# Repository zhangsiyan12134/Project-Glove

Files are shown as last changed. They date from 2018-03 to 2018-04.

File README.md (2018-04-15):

# Project-Glove<br />
This project is to create a hand glove that capture motions to control a computer or other
devices. It will increase capacity of control in VR and other computer systems. The range of
motion will change from pushing buttons and triggers to active movements of the hands.

This is a 2nd Year Engineeing Design II Group Project at Acadia University.<br />

**Group 12**<br />

Omar H. Khattab/ Project Manager<br />
Hannah MacCormnack/ Project Researcher<br />
Haolin Song/ Project Designer<br />
Siyan Zhang/ Project Technican<br />

**Current State**<br />
The basic function of mouse is working, but due to the limited performance and pooly optimized code, add any additional function will causes signifecant delay of the motion.

**Todo List**<br />
1. Simplify the code to make code more efficiency.
2. Waiting for **New** ATSAMD51 series with hardware DSP and Float Point support.

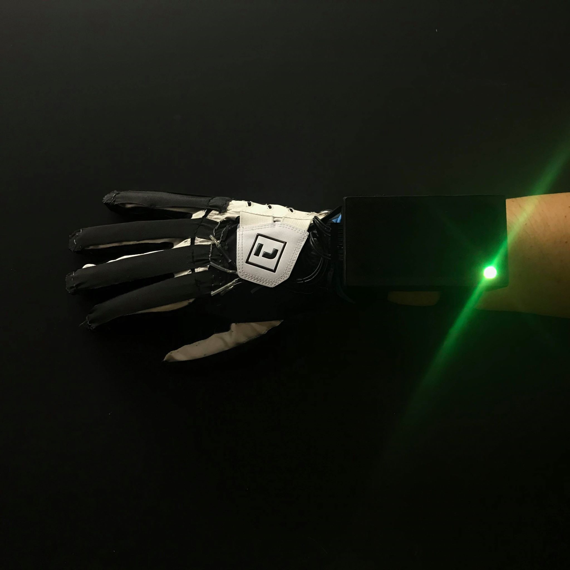
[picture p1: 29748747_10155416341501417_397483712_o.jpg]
Image of Glove


Demo Video：https://youtu.be/c8829fM5WGY

**Parts List**<br />

Part     Value          Device             Package         Library           Sheet<br />

MS1                     FEATHERM0BLE       FEATHER         adafruit          1<br />
U$1                     Adafruit BNO055    BNO055          Adafruit_BNO055   1<br />
MODESW                  OS102011MA1Q       OS102011MA1Q    adafruit          1<br />
PSW                     OS102011MA1Q       OS102011MA1Q    adafruit          1<br />
D1       CLEAR          LED-RGB-CACLEAR    LED-RGB-THRU    SparkFun-LED      1<br />
R1       200            R-US_0207/7        0207/7          resistor          1<br />
R2       200            R-US_0207/7        0207/7          resistor          1<br />
R3       200            R-US_0207/7        0207/7          resistor          1<br />
R4       10k            R-US_0207/7        0207/7          resistor          1<br />
R5       10k            R-US_0207/7        0207/7          resistor          1<br />
R6       10k            R-US_0207/7        0207/7          resistor          1<br />
R7       10k            R-US_0207/7        0207/7          resistor          1<br />
JP1                     PINHD-1X8          1X08            pinhead           1<br />

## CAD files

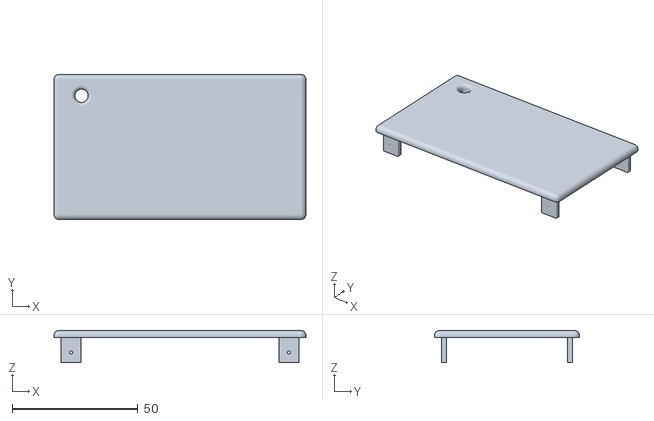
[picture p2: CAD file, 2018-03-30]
Case Design/Top Cover.stl
100.0 x 57.6 x 12.8

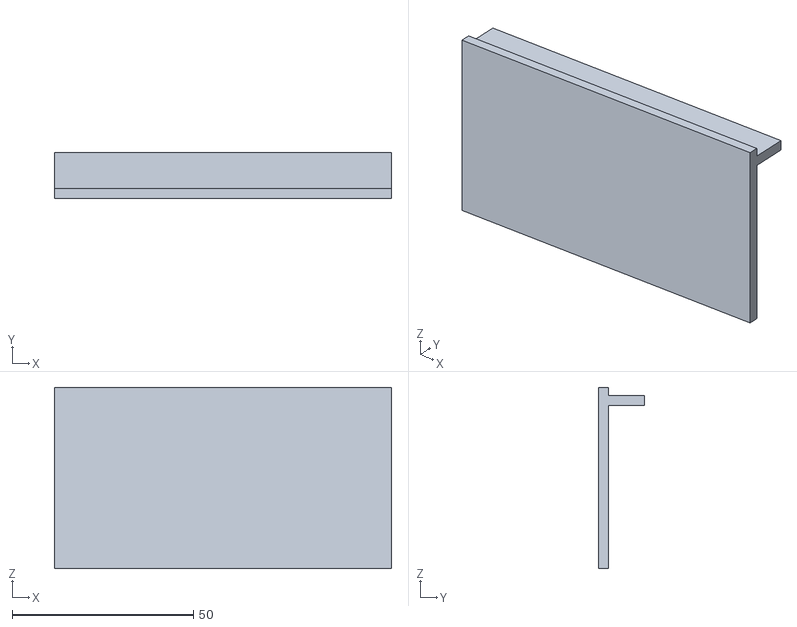
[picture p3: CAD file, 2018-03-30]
Case Design/Insert.stl
93.0 x 12.8 x 50.0

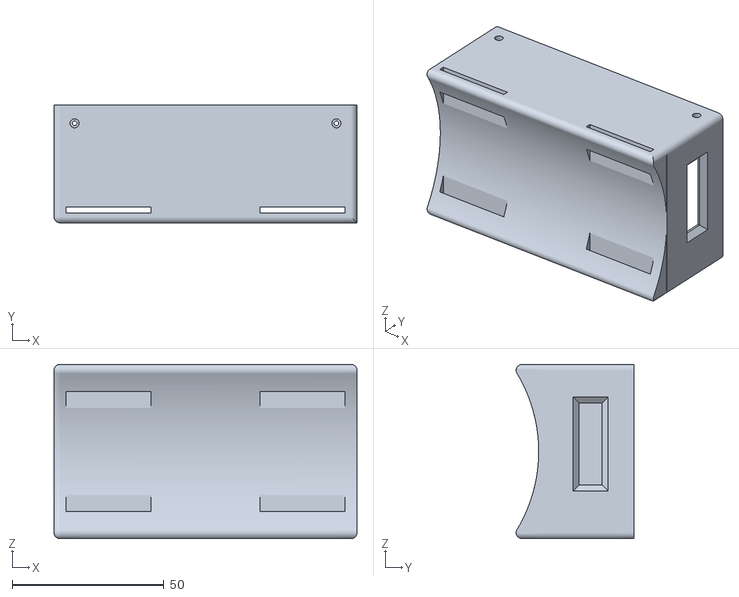
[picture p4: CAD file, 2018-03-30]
Case Design/Body.stl
100.0 x 38.8 x 57.6

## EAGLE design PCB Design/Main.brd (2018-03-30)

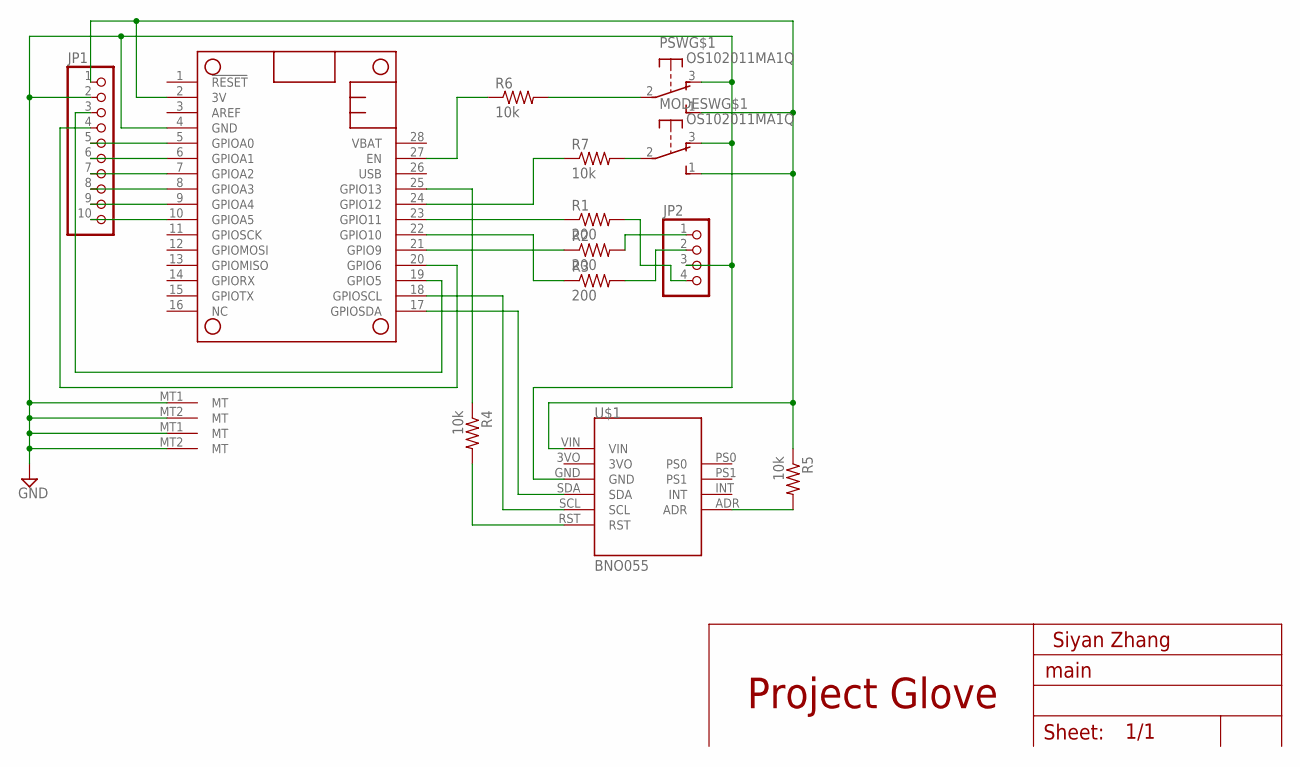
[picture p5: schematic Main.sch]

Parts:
JP1: PINHD-1X10; 1X10
JP2: PINHD-1X4; 1X04
MODESW: OS102011MA1Q
MS1: FEATHERWING
PSW: OS102011MA1Q
R1, R2, R3: 200; 0207/7
R4, R6, R7: 10k; 0207/7
R5: 10k; 0207/15
U$1: BNO055

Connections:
3V: JP1.1, MODESW.1 (S), MS1.2 (3V), PSW.1 (S), R5.1, U$1.VIN
GND: JP1.2, JP2.3, MODESW.3 (O), MODESW.MT1 (MT), MODESW.MT2 (MT), MS1.4 (GND), PSW.3 (O), PSW.MT1 (MT), PSW.MT2 (MT), U$1.GND
unnamed: MODESW.2, R7.2
unnamed: MS1.24 (GPIO12), R7.1
unnamed: MS1.22 (GPIO10), R3.1
unnamed: MS1.21 (GPIO9), R2.1
unnamed: MS1.23 (GPIO11), R1.1
unnamed: JP2.4, R1.2
unnamed: JP2.1, R2.2
unnamed: JP2.2, R3.2
unnamed: JP1.10, MS1.10 (GPIOA5)
unnamed: JP1.9, MS1.9 (GPIOA4)
unnamed: JP1.8, MS1.8 (GPIOA3)
unnamed: JP1.7, MS1.7 (GPIOA2)
unnamed: JP1.6, MS1.6 (GPIOA1)
unnamed: MS1.17 (GPIOSDA), U$1.SDA
unnamed: MS1.18 (GPIOSCL), U$1.SCL
unnamed: R4.2, U$1.RST
unnamed: R5.2, U$1.ADR
unnamed: MS1.25 (GPIO13), R4.1
unnamed: JP1.5, MS1.5 (GPIOA0)
unnamed: PSW.2, R6.2
unnamed: MS1.27 (EN), R6.1
unnamed: JP1.3, MS1.19 (GPIO5)
unnamed: JP1.4, MS1.20 (GPIO6)

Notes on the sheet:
Sheet:
Project Glove
Siyan Zhang

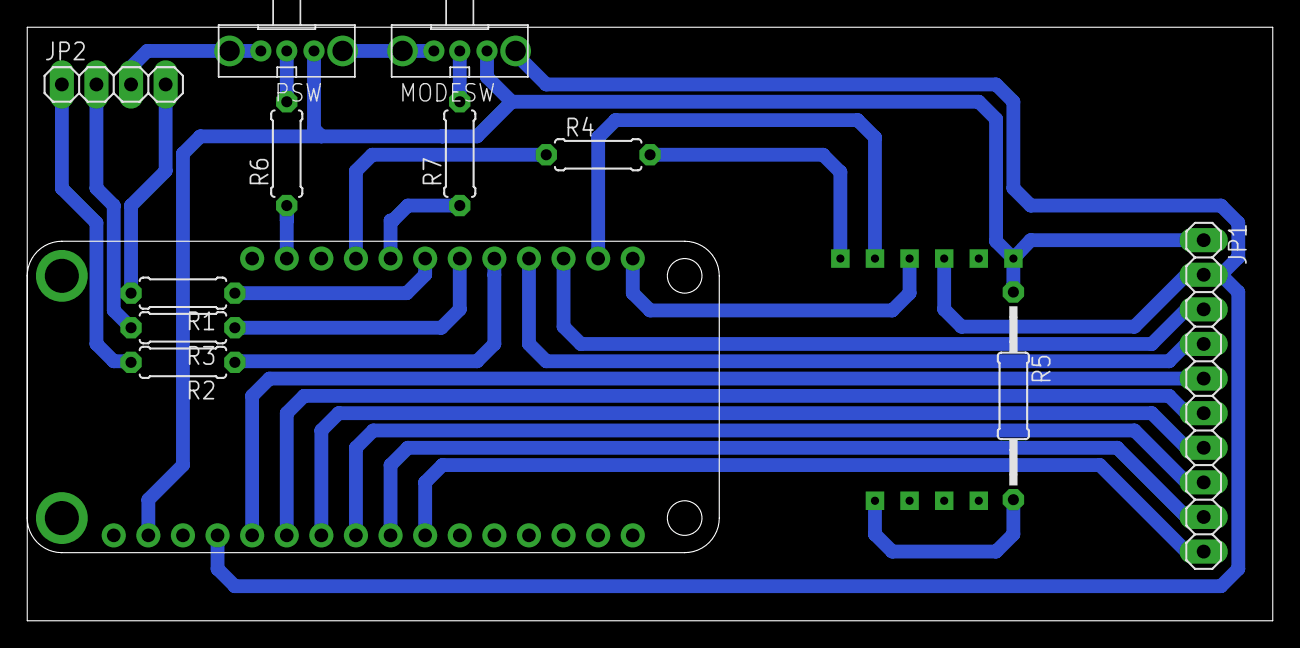
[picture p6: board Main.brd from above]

Board: 2 copper layers, 91.4 x 43.6 mm, 14 parts (0 on the bottom side), 25 nets.

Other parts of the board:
U$2: A4L-LOC

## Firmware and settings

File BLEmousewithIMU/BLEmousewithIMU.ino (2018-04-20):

/*
This is the program for Adafruit Feather M0 Bluefruit LE with Adafruit BNO055 IMU Module.
In theory, it can be directly uses on Arduino M0 with Adafruit Bluefruit LE SPI Friend and Adafruit BNO055 IMU Module.
*/

//include libraries for microcontroller and BLE module
#include "BluefruitConfig.h"
#include <Arduino.h>
#include <SPI.h>
#include "Adafruit_BLE.h"
#include "Adafruit_BluefruitLE_SPI.h"
#include "Adafruit_BluefruitLE_UART.h"

//include libraries for IMU
#include <Wire.h>
#include <Adafruit_Sensor.h>
#include <Adafruit_BNO055.h>
#include <utility/imumaths.h>

//Set IMU sample rate and rename the sensor in bno
#define BNO055_SAMPLERATE_DELAY_MS (10)
Adafruit_BNO055 bno = Adafruit_BNO055();

//define all the pin numbers

#define thumb A1
#define index A2
#define middle A3
#define ring A4
#define pinky A5

#define ModeSW 12

#define rgbRed 11
#define rgbGreen 10
#define rgbBlue 9

//settings for the project
const int sensitivity = 22; //sensitivity of the movement
const int debug = 1; //Debug flag

//initialize all global variables 
int xMove, yMove, drift, b;
float _x0, _y0;
float _x1, _y1, _z1, _x2, _y2;

/*=========================================================================
    APPLICATION SETTINGS

    FACTORYRESET_ENABLE       Perform a factory reset when running this sketch
   
                              Enabling this will put your Bluefruit LE module
                              in a 'known good' state and clear any config
                              data set in previous sketches or projects, so
                              running this at least once is a good idea.
   
                              When deploying your project, however, you will
                              want to disable factory reset by setting this
                              value to 0.  If you are making changes to your
                              Bluefruit LE device via AT commands, and those
                              changes aren't persisting across resets, this
                              is the reason why.  Factory reset will erase
                              the non-volatile memory where config data is
                              stored, setting it back to factory default
                              values.
       
                              Some sketches that require you to bond to a
                              central device (HID mouse, keyboard, etc.)
                              won't work at all with this feature enabled
                              since the factory reset will clear all of the
                              bonding data stored on the chip, meaning the
                              central device won't be able to reconnect.
    MINIMUM_FIRMWARE_VERSION  Minimum firmware version to have some new features
    -----------------------------------------------------------------------*/
    #define FACTORYRESET_ENABLE         0
    #define MINIMUM_FIRMWARE_VERSION    "0.6.6"
/*=========================================================================*/


// Create the bluefruit object, either software serial...uncomment these lines

/* ...hardware SPI, using SCK/MOSI/MISO hardware SPI pins and then user selected CS/IRQ/RST */
Adafruit_BluefruitLE_SPI ble(BLUEFRUIT_SPI_CS, BLUEFRUIT_SPI_IRQ, BLUEFRUIT_SPI_RST);

// A small helper
void error(const __FlashStringHelper*err) {
  Serial.println(err);
  while (1);
}

/**************************************************************************/
/*!
    @brief  Sets up the HW an the BLE module (this function is called
            automatically on startup)
*/
/**************************************************************************/

int getBattery(void){
//Convert battery voltage into 0~255 reading	
	int value;
	value = (analogRead(A7)*6.6/4096);
	return map(value, 3.2, 4.2, 0, 255);
}

int LEDWrite(int R, int G){
//lit RGB LED with Green and Red.	
	analogWrite(rgbRed, R);
	analogWrite(rgbGreen, G);
}

int FadeIn(int Pin){
  //Lit cycle for RGB LED throught mixture of red, green and blue
  for (int fadeValue = 0 ; fadeValue <= 255; fadeValue += 5) {
    // sets the value (range from 0 to 255):
    analogWrite(Pin, fadeValue);
    // wait for 30 milliseconds to see the dimming effect
    delay(30);
  }
  return 0;
}

int FadeOut(int Pin){
//Off cycle for RGB LED throught mixture of red, green and blue
  for (int fadeValue = 255 ; fadeValue >= 0; fadeValue -= 5) {
    // sets the value (range from 0 to 255):
    analogWrite(Pin, fadeValue);
    // wait for 30 milliseconds to see the dimming effect
    delay(30);
  }
  return 0;    
}

int cmove(int x, int y){
//send move data of mouse curser to bluetooth module according to the given x,y value.
     ble.print(F("AT+BleHidMouseMove="));
     ble.print(x);
     ble.print(",");
     ble.println(y);
     return 0;
}

int fingerRead(int finger, int offset){
//read one finger and give back a reading inbetween 0~4095
  int reading;
  reading = analogRead(finger)-offset;

  return reading; //map(reading,0,4095,0,512);
}

int LeftClick(void){
/*
Read fingers and compare to the thresholds, adjust thresholds and fingers with debug flag enabled.
Reading from finger is in between 0 to 4095.
All five fingers are avaliable as input(thumb, index, middle, ring and pinky).
*/
  int data = 0;
  for( int i=0; i <= 10; i++){
    if(fingerRead(middle, 0)> 2000 && fingerRead(ring, 0)> 2300){
	data += 1;
     } else {
	data += 0;
     }
  }
  /*
  to filter the noise, the following lines are averaging how many reading is higher
  than the thresholds in given numbers of continuous samples to be considered as a valid 
  click. (in this case 85% reading has to be higher than thresholds in 10 continuous 
  samples)  
  */
  if(data/10 >= 0.85){
	return 1;
  } else {
	return 0;
  }
}

void setup(void){

  while (!Serial and debug);  // required for Flora & Micro
  delay(500);

  Serial.begin(115200);

  pinMode(ModeSW,INPUT);
  
  ADC->INPUTCTRL.bit.GAIN = ADC_INPUTCTRL_GAIN_2X_Val; //Set internal gain
  ADC->REFCTRL.bit.REFSEL = ADC_REFCTRL_REFSEL_INTVCC0_Val;
  //ADC->AVGCTRL.bit.SAMPLENUM = ADC_AVGCTRL_SAMPLENUM_8_Val; // average from 4 samples
  analogReadResolution(12); //Change the ADC resolution to 12 bits 

  //initialize IMU module
  if(!bno.begin())
  {
    /* There was a problem detecting the BNO055 ... check your connections */
    Serial.print("Ooops, no BNO055 detected ... Check your wiring or I2C ADDR!");
    while(1);
  }
  bno.setExtCrystalUse(true); //set IMU module to use external crystal 

  //Initialise the BLU module
  Serial.print(F("Initialising the Bluefruit LE module: "));

  if ( !ble.begin(VERBOSE_MODE) ) //
  {
    error(F("Couldn't find Bluefruit, make sure it's in CoMmanD mode & check wiring?"));
  }
  Serial.println( F("OK!") );

  if ( FACTORYRESET_ENABLE )
  {
    /* Perform a factory reset to make sure everything is in a known state */
    Serial.println(F("Performing a factory reset: "));
    if ( ! ble.factoryReset() ){
      error(F("Couldn't factory reset"));
    }
  }

  /* Disable command echo from Bluefruit */
  ble.echo(false);

  Serial.println("Requesting Bluefruit info:");
  /* Print Bluefruit information */
  ble.info();

  // This demo only available for firmware from 0.6.6
  if ( !ble.isVersionAtLeast(MINIMUM_FIRMWARE_VERSION) )
  {
    error(F("This sketch requires firmware version " MINIMUM_FIRMWARE_VERSION " or higher!"));
  }

  /* Enable HID Service (including Mouse) */
  Serial.println(F("Enable HID Service (including Mouse): "));
  if (! ble.sendCommandCheckOK(F( "AT+BleHIDEn=On"  ))) {
    error(F("Failed to enable HID (firmware >=0.6.6?)"));
  }

  /* Add or remove service requires a reset */
  Serial.println(F("Performing a SW reset (service changes require a reset): "));
  if (! ble.reset() ) {
    error(F("Could not reset??"));
  }
  Serial.println();
    
}

/**************************************************************************/
/*!
    @brief  Constantly poll for new command or response data
*/
/**************************************************************************/
void loop(void){
//Two main loops for enable and disable function	
  while(digitalRead(ModeSW) == 1){

    imu::Vector<3> euler = bno.getVector(Adafruit_BNO055::VECTOR_EULER); //get euler angle from IMU

    _x1 = (euler.x());
    _y1 = (euler.y());
    _z1 = (euler.z());

    _y2 = _y1- _y0;  //compare the current reading to previous reading to see how far hand was moved
    _x2 = _x1- _x0;
    _y0 = _y1;  //Store current readings for next cycle
    _x0 = _x1; 
	
    if (_y2 != 0 or _x2 != 0){
	xMove = _x2 * sensitivity * 1.5;  //screen has greater length than width, times 1.5
        yMove = -(_y2) * sensitivity * 1;
	//remove slight drifting when hand is not moving.    
	if(yMove > 0){
		drift = 1;
	} else if(yMove < 0){
		drift = -1;
	} else {drift = 0;}
		
	if(xMove > 0){
		drift = 1;
	} else if(xMove < 0){
		drift = -1;
	} else {drift = 0;}
		
        cmove(xMove-drift, yMove-drift); // send data and move mouse
	}
	
    /******************************************************/
    /*if (_y2 != 0){
        yMove = -(_y2) * sensitivity * 1.8;
		if(yMove > 0){
			drift = 1;
		} else if(yMove < 0){
			drift = -1;
		} else {drift = 0;}
		
        cmove(0, yMove-drift); // move mouse on y axis
	}
	  
    if (_x2 != 0){
        xMove = _x2 * sensitivity;
		if(xMove > 0){
			drift = 1;
		} else if(xMove < 0){
			drift = -1;
		} else {drift = 0;}
		cmove(xMove-drift, 0); // move mouse on x axis
	}*/
	/******************************************************/
    
    if(LeftClick() == 1){
      ble.sendCommandCheckOK(F("AT+BleHidMouseButton=L,press"));
    }
    if(LeftClick() == 0){
      ble.sendCommandCheckOK(F("AT+BleHidMouseButton=0"));
    }
	
    if(debug){
    //print real time reading to serial port(may lagging the movement)
	Serial.print(xMove-drift);
	Serial.print(",");
	Serial.print(yMove-drift);
	Serial.print(",");
	Serial.print(fingerRead(index, 0));
	Serial.print(",");
	Serial.print(fingerRead(middle, 0));
	Serial.print(",");
	Serial.print(fingerRead(ring, 0));
	Serial.print(",");
	Serial.println(LeftClick());
    }
  }  
  //second main loop
  while(digitalRead(ModeSW) == 0){
	FadeIn(rgbRed);
	delay(1000);
	FadeIn(rgbGreen);
	delay(1000);
	FadeIn(rgbBlue);
	delay(1000);

	FadeOut(rgbRed);
	delay(1000);
	FadeOut(rgbGreen);
	delay(1000);
	FadeOut(rgbBlue);
	delay(1000);
  }
}

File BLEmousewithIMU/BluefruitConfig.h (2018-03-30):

// COMMON SETTINGS
// ----------------------------------------------------------------------------------------------
// These settings are used in both SW UART, HW UART and SPI mode
// ----------------------------------------------------------------------------------------------
#define BUFSIZE                        128   // Size of the read buffer for incoming data
#define VERBOSE_MODE                   false  // If set to 'true' enables debug output


// SOFTWARE UART SETTINGS
// ----------------------------------------------------------------------------------------------
// The following macros declare the pins that will be used for 'SW' serial.
// You should use this option if you are connecting the UART Friend to an UNO
// ----------------------------------------------------------------------------------------------
#define BLUEFRUIT_SWUART_RXD_PIN       9    // Required for software serial!
#define BLUEFRUIT_SWUART_TXD_PIN       10   // Required for software serial!
#define BLUEFRUIT_UART_CTS_PIN         11   // Required for software serial!
#define BLUEFRUIT_UART_RTS_PIN         -1   // Optional, set to -1 if unused


// HARDWARE UART SETTINGS
// ----------------------------------------------------------------------------------------------
// The following macros declare the HW serial port you are using. Uncomment
// this line if you are connecting the BLE to Leonardo/Micro or Flora
// ----------------------------------------------------------------------------------------------
#ifdef Serial1    // this makes it not complain on compilation if there's no Serial1
  #define BLUEFRUIT_HWSERIAL_NAME      Serial1
#endif


// SHARED UART SETTINGS
// ----------------------------------------------------------------------------------------------
// The following sets the optional Mode pin, its recommended but not required
// ----------------------------------------------------------------------------------------------
#define BLUEFRUIT_UART_MODE_PIN        12    // Set to -1 if unused


// HARDWARE SPI SETTINGS
// ----------------------------------------------------------------------------------------------
// The following macros declare the pins to use for HW SPI communication.
// SCK, MISO and MOSI should be connected to the HW SPI pins on the Uno, etc.
// This should be used with nRF51822 based Bluefruit LE modules that use SPI.
// ----------------------------------------------------------------------------------------------
#define BLUEFRUIT_SPI_CS               8
#define BLUEFRUIT_SPI_IRQ              7
#define BLUEFRUIT_SPI_RST              4    // Optional but recommended, set to -1 if unused

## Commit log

2018-03-30 Rename Glove/Adafruit_BNO055.lbr to PCB Design/Adafruit_BNO055.lbr
2018-03-30 Rename Glove/Main.brd to PCB Design/Main.brd
    [Main.brd]
2018-03-30 Rename Glove/Main.sch to PCB Design/Main.sch
    [Main.sch]
2018-03-30 Rename Glove/eagle.epf to PCB Design/eagle.epf
2018-04-20 Update BLEmousewithIMU.ino
    Add more comments about how to calibrate the glove.
